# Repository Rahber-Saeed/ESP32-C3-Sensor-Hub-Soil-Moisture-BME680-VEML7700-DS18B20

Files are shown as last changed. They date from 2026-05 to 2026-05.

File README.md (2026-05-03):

# ESP32-C3-Sensor-Hub-Soil-Moisture-BME680-VEML7700-DS18B20
A feature-packed, portable open-source hardware sensor board built around the ESP32-C3. It integrates soil moisture monitoring, environmental sensing (BME680), light sensing (VEML7700), temperature sensing (DS18B20), complete Li-ion battery management (TP4056 + DW01A Protection), and automatic power switching.
# 🌱 ESP32-C3 Multi-Sensor & Plant Monitor Board

A compact, all-in-one development board designed for effortless IoT sensing and portable applications. It features a complete suite of sensors, robust Li-ion power management, and a convenient USB-C interface.

> ⚠️ **Note:** This is an open-source hardware project. Please refer to the BOM and Pick-And-Place files for the exact components required for assembly.

---

## ✨ Key Features

*   **Core Controller:** ESP32-C3 SuperMini (also compatible with ESP32-S3 SuperMini).
*   **Sensor Suites:**
    *   **🌱 Soil Moisture:** LM393 comparator with indicator LEDs and PH Connector.
    *   **🌫️ Environmental:** BME680 (Gas, Temp, Humidity, Pressure).
    *   **☀️ Light:** VEML7700 Ambient Light Sensor (I2C).
    *   **🌡️ Temperature:** DS18B20 One-Wire Digital Sensor.
*   **Power Management (Robust):**
    *   **TP4056:** Li-ion/Li-Po battery charging over USB-C.
    *   **DW01A + FS8205A:** Over-charge/Over-discharge protection.
    *   **Auto Power Switching:** Seamless transition between USB and Battery power via DMP1045U.
*   **Connectivity & Interface:**
    *   2x Qwiic I2C connectors for easy expansion.
    *   USB-C for data and charging.
    *   Status LEDs for Power, Bluetooth, and WiFi.
*   **User Controls:** Power Switch, Reset Button, Sleep Button.

---

## 🖼️ Gallery

Schematic_ESP-C3-supermini-based-Project_2026-05-03

| PCB Top | PCB Bottom | PCB 3D |
ESP-C3 supermini based Project_3D_Top_View

| :---: | :---: | :---: |

| PCB Top | PCB Bottom | PCB 3D |

*(Note: Ensure you place your uploaded images into an `images/` folder)*
ESP-C3 supermini based Project_3D_Bottom_View

---
ESP-C3 supermini based Project_2D_View

## 📜 Schematic & PCB

*   **Schematic:** [`Schematic_ESP-C3-supermini-based-Project_2026-05-03.pdf`](Schematic_ESP-C3-supermini-based-Project_2026-05-03.pdf)
*   **PCB Layout:** [`PCB_PCB_PCB_ESP-C3-supermini-based-Project_2025-07-15_2026-05-03.pdf`](PCB_PCB_PCB_ESP-C3-supermini-based-Project_2025-07-15_2026-05-03.pdf)

---

## 📦 Bill of Materials (BOM)

The complete BOM is available in the file [`BOM_ESP-C3-supermini-based-Project_2026-05-03.csv`](BOM_ESP-C3-supermini-based-Project_2026-05-03.csv).

| Component Type | Part | Description |
| :--- | :--- | :--- |
| **MCU** | ESP32-C3 SuperMini | Main WiFi/BLE Controller |
| **Power** | TP4056, DW01A, FS8205A | Battery Charger + Protection |
| **Sensors** | BME680, VEML7700, DS18B20 | Environmental, Light, Temp |
| **UI** | LM393, LEDs, Switches | Soil Moisture Detection, Status LEDs |

---

## 🔌 Pinout & Connections

This pinout is based on the provided schematic. Please verify with the final PCB layout.

| Function | Component | Pin (ESP32-C3 SuperMini) |
| :--- | :--- | :--- |
| **I2C** | SDA (VEML7700, BME680, Qwiic) | GPIO 5 |
| | SCL (VEML7700, BME680, Qwiic) | GPIO 4 |
| **OneWire** | DS18B20 | GPIO 2 |
| **Soil Moisture** | Digital Output (PH Connector U9) | GPIO 9 (SPI_CS1) |
| **Status LEDs** | WiFi Indicator (LED1) | GPIO 12 |
| | Bluetooth Indicator (LED2) | GPIO 13 |
| **Power** | Auto Power Switching P-MOSFET (Q1) | GPIO 0 |

*(Note: Pin mappings are based on the schematic. Refer to the ESP32-C3 datasheet for alternative configurations or if using the ESP32-S3 module).*

---

## 🛠️ Getting Started / Programming

1.  **Order the PCB:** Upload the `PCB_PCB_PCB...pdf` to a manufacturer like JLCPCB or PCBWay.
2.  **Solder Components:** Assemble the board using the BOM and Pick-And-Place CSV file.
3.  **Code Setup:**
    *   Select the `ESP32C3 Dev Module` in Arduino IDE or PlatformIO.
    *   **Libraries:**
        *   `Adafruit BME680`
        *   `Adafruit VEML7700`
        *   `OneWire` & `DallasTemperature` (for DS18B20).
4.  **Upload:** Connect via USB-C, select correct COM port, and upload your code.

---

## 📂 Repository Structure

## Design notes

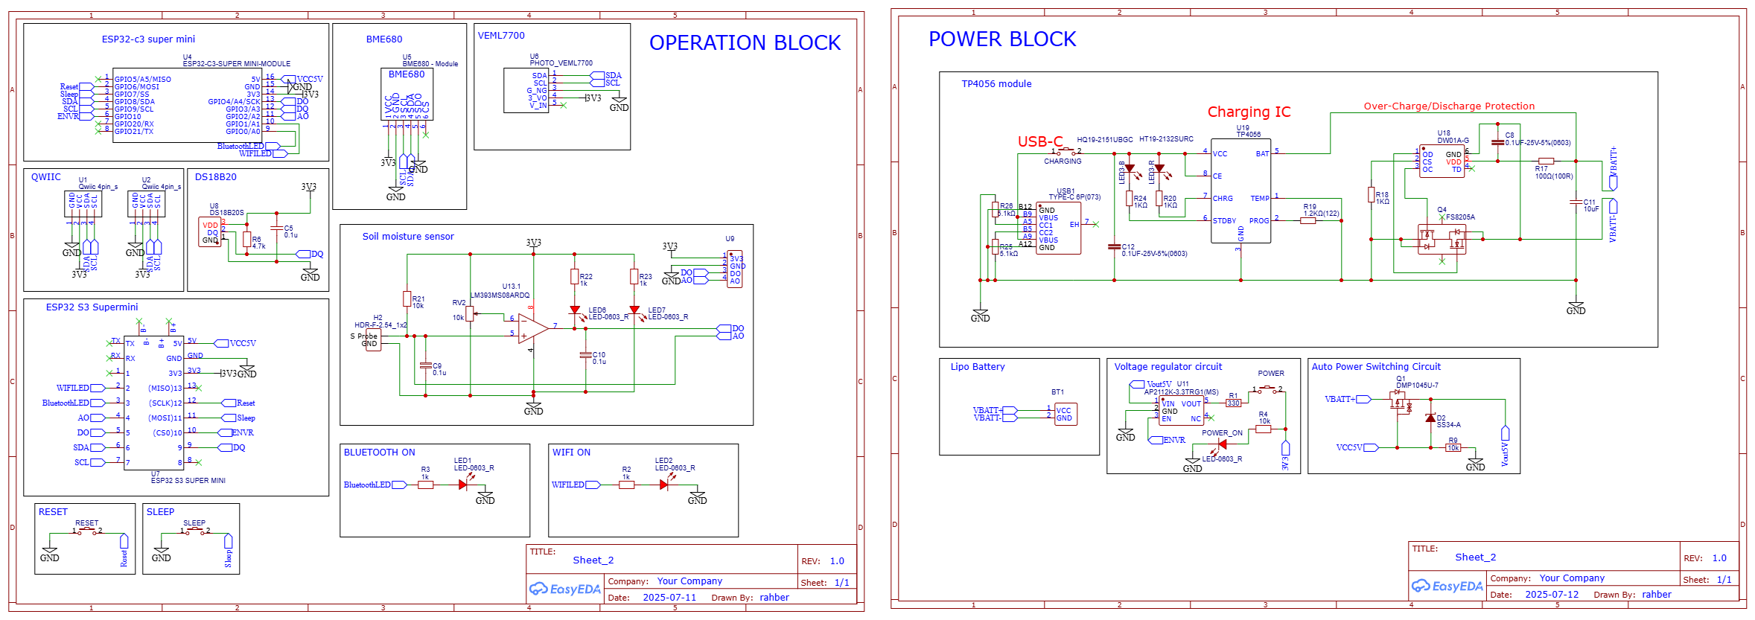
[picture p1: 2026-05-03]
Schematic_ESP-C3-supermini-based-Project_2026-05-03.png

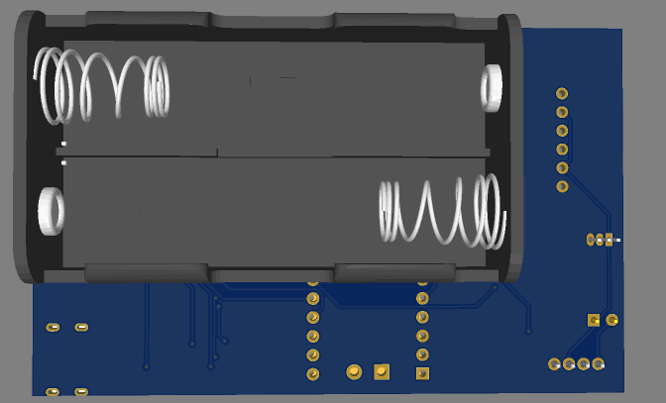
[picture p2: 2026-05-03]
ESP-C3 supermini based Project_3D_Bottom_View.png

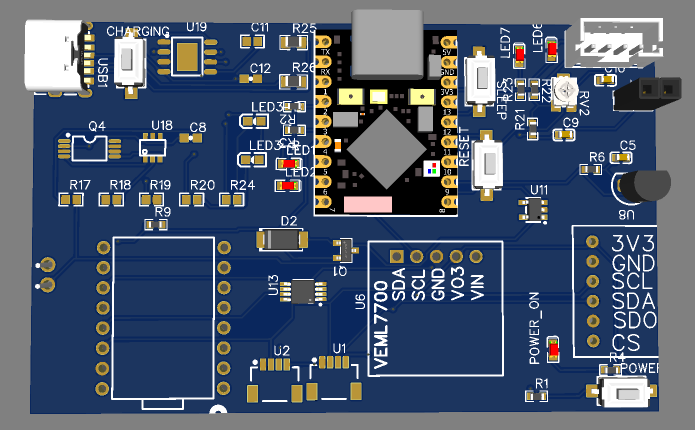
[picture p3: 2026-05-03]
ESP-C3 supermini based Project_3D_Top_View.png

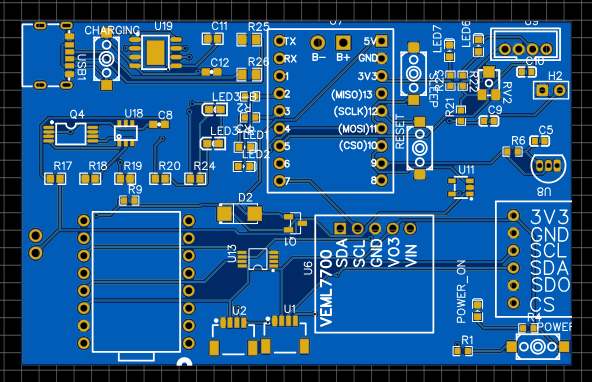
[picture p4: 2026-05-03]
ESP-C3 supermini based Project_2D_View.png

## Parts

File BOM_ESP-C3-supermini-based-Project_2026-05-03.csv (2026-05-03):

ID | Name | Designator | Footprint | Quantity | Manufacturer Part | Manufacturer | Supplier | Supplier Part | Price | Pins | 3DModel | Contributor | JLCPCB Part Class | LCSC Assembly | Package Display | Power (Watts) | Rated Voltage | Tolerance | image | link | subpart_no | 制造商
1 | 0.1u | C5,C9,C10 | C0603 | 3 |  |  |  |  |  | 2 | C0603_L1.6-W0.8-H0.8 | LCEDA_Lib |  |  |  |  |  |  |  | https://item.szlcsc.com/362304.html
2 | SS34-A | D2 | SMA_L4.3-W2.6-LS5.2-RD | 1 | SS34-A | FMS(美丽微) | LCSC | C143201 | 0.053 | 2 | SMA_L4.3-W2.6-LS5.2-RD | LCSC | Extended Part |  |  |  |  |  |  | https://item.szlcsc.com/34721.html
3 | LED-0603_R | LED6,LED7,LED1,LED2,POWER_ON | LED0603_RED | 5 | 19-217/R6C-AL1M2VY/3T | EVERLIGHT(台湾亿光) | LCSC | C72044 | 0.021 | 2 | LED0603_Red | LCEDA_01
4 | DMP1045U-7 | Q1 | SOT-23-3_L2.9-W1.3-P1.90-LS2.4-BR | 1 | DMP1045U-7 | DIODES(美台) | LCSC | C177033 | 0.159 | 3 | SOT-23-3P_L2.9-W1.3-H1.0-LS2.4-P0.95 | LCSC | Extended Part |  |  |  |  |  |  | https://www.diodes.com/assets/Package-Files/SOT23.pdf
5 | 4.7k | R6 | R0603 | 1 |  |  |  |  |  | 2 | R0603 | LCEDA_Lib |  |  |  |  |  |  |  | https://www.mouser.in/datasheet/2/447/PYu_RT_1_to_0_01_RoHS_L_11-1669912.pdf
6 | 10k | R9,R21,R4 | R0603 | 3 |  |  |  |  |  | 2 | R0603 | LCEDA_Lib |  |  |  |  |  |  |  | https://www.mouser.in/datasheet/2/447/PYu_RT_1_to_0_01_RoHS_L_11-1669912.pdf
7 | 1k | R22,R23,R2,R3 | R0603 | 4 |  |  |  |  |  | 2 | R0603 | LCEDA_Lib |  |  |  |  |  |  |  | https://www.mouser.in/datasheet/2/447/PYu_RT_1_to_0_01_RoHS_L_11-1669912.pdf
8 | 10k | RV2 | RES-ADJ-SMD_VG039NCH | 1 | 3*3Potentiometer-10kΩ20% | null | LCSC | C9900010776 |  | 3 | RES-ADJ-SMD_3P-L3.8-W3.0-H1.2-P1.90 | LCSC | Extended Part |  |  |  |  |  |  | https://item.szlcsc.com/139841.html
9 | ESP32-C3-SUPER MINI-MODULE | U4 | ESP32-C3-SUPER-MINI-MODULE | 1 |  |  |  |  |  | 16 |  | microactuator
10 | BME680 - Module | U5 | BME680PCB | 1 | New SchematicLib |  | DFRobot |  |  | 6 |  | chrisrisse
11 | PHOTO_VEML7700 | U6 | PHOTO_VEML7700_F | 1 | PHOTO_VEML7700 |  |  |  |  | 5 |  | shinkyusik
12 | DS18B20S | U8 | TO-92-3_L4.9-W3.7-P1.27-L | 1 | MYDS18B20S | Mysentech(敏源传感) | LCSC | C41361412 | 0.292 | 3 | TO-92-3_L4.9-W3.7-P1.27-L | lcsc |  |  |  |  |  |  |  | https://atta.szlcsc.com/upload/public/pdf/source/20180629/C233232_99576441F8ED8E9074FB1575A6BE3592.PDF
13 | PH-CONNECTOR 01.08.40.001.001 | U9 | CONN-TH_PH-CONNECTOR01.08.40.001.001 | 1 | PH-CONNECTOR 01.08.40.001.001 | null | LCSC | C9900005438 |  | 4 | CONN-TH_PH-CONNECTOR01.08.40.001.001 | LCSC | Extended Part |  |  |  |  |  |  | https://img.jlc.com/image//data/smt-stock-produce/componentSizePhoto/2022-01-04/19bec1aa099f49cab68d79e3ac0b8296/BG2112310476_D21122700130_font.png
14 | AP2112K-3.3TRG1(MS) | U11 | SOT-23-5_L2.9-W1.6-P0.95-LS2.7-BR | 1 | AP2112K-3.3TRG1(MS) | MSKSEMI(美森科) | LCSC | C22365427 | 0.073 | 5 | SOT-23-5_L2.9-W1.6-P0.95-LS2.7-BR | lcsc | Extended Part |  |  |  |  |  |  | https://atta.szlcsc.com/upload/public/pdf/source/20210222/C616245_2EB3813F1C3E67808D09ADFA7C45AA77.pdf
15 | LM393MS08ARDQ | U13 | MSOP-8_L3.0-W3.0-P0.65-LS4.9-BL-1 | 1 | LM393MS08ARDQ | GR(国睿) | LCSC | C46527059 | 0.089 | 8 | MSOP-8_L3.0-W3.0-P0.65-LS4.9-BL-1 | lcsc | Extended Part |  |  |  |  |  |  | https://atta.szlcsc.com/upload/public/pdf/source/20200925/C726653_8C4DEEE918D81B4566489376FD74F88A.pdf | 1
16 | HDR-F-2.54_1x2 | H2 | HDR-F-2.54_1X2 | 1 |  |  | LCSC | C49661 | 0.061 | 2 | HDR-F-2.54_1x2 | LCEDA_Lib
17 | ESP32 S3 SUPER MINI | U7 | ESP32-S3-SUPERMINI-MAXS | 1 |  |  |  |  |  | 20 | SuperMini ESP32-S3_TrueSize | maxanthonyfloreztapia
18 | 0.1UF-25V-5%(0603) | C8,C12 | 0603-CAP | 2 | ? |  |  |  |  | 2 |  | SparkFun
19 | 10uF | C11 | 0603 | 1 | 0603X106K160NT | FH | LCSC | C70225 | 0.029 | 2 |  |  |  |  |  |  | 16V | ±10%
20 | HQ19-2151UBGC | LED3-B | LED-0603 | 1 | HQ19-2151UBGC | HARVATEK | LCSC | C154450 |  | 2 |  | LCSC
21 | HT19-2132SURC | LED3-R | LED-0603 | 1 | HT19-2132SURC | HARVATEK | LCSC | C154453 |  | 2 |  | LCSC
22 | FS8205A | Q4 | TSSOP-8_3X4.4X065P | 1 | FS8205A | FORTUNE | LCSC | C16052 | 0.119 | 8 |  | Guest |  | Yes |  |  |  |  | //image.lceda.cn/szlcsc/C16052.jpg
23 | 100Ω(100R) | R17 | 0603 | 1 | AC0603FR-07100RL | YAGEO | LCSC | C125923 | 0.002 | 2 |  |  |  |  |  | 1/10W |  | ±1%
24 | 1KΩ | R18,R20,R24 | 0603 | 3 | RC0603FR-071KL | YAGEO | LCSC | C22548 | 0.002 | 2 |  |  |  |  |  | 1/10W |  | ±1%
25 | 1.2KΩ(122) | R19 | 0603 | 1 | RC0603JR-071K2L | YAGEO | LCSC | C114679 | 0.002 | 2 |  |  |  |  |  | 1/10W |  | ±5%
26 | 5.1kΩ | R25,R26 | R0805 | 2 | 0805W8F5101T5E | UNI-ROYAL(厚声) | LCSC | C27834 | 0.003 | 2 | R0805_L2.0-W1.3-H0.6 | lcsc | Basic Part |  |  |  |  |  |  | https://item.szlcsc.com/142685.html
27 | DW01A-G | U18 | SOT-23-6 | 1 | DW01A-G | FORTUNE | LCSC | C61503 | 0.078 | 6 |  | LCSC
28 | TP4056 | U19 | SOP-8_EP_150MIL | 1 | TP4056 | TOPPOWER | LCSC | C16581 | 0.186 | 9 |  | Guest |  | Yes | No |  |  |  | //image.lceda.cn/szlcsc/C16581.jpg
29 | Qwiic 4pin_s | U1,U2 | QWIIC 4PIN | 2 |  |  |  |  |  | 6 |  | PeterL
30 | TYPE-C 6P(073) | USB1 | TYPE-C-SMD_TYPE-C-6P-073 | 1 | TYPE-C 6P(073) | SHOU HAN(首韩) | LCSC | C668623 | 0.04 | 10 | TYPE-C-SMD_TYPE-C-6P-073 | LCSC | Extended Part |  |  |  |  |  |  | https://item.szlcsc.com/datasheet/TYPE-C%25206P(073)/698566.html
31 | K2-3.6×6.1_SMD | CHARGING,POWER,RESET,SLEEP | KEY-SMD_2P-L6.2-W3.6-LS8.0 | 4 | K2-1107ST-A4SW-06 |  | LCSC | C118141 | 0.074 | 2 | KEY-SMD_2P-L6.2-W3.6-LS8.0 | LCEDA_Lib |  |  |  |  |  |  |  | https://so.szlcsc.com/global.html?c=&k=C498306 |  | 韩国韩荣
32 | 330 | R1 | R0603 | 1 |  |  |  |  |  | 2 | R0603 | LCEDA_Lib |  |  |  |  |  |  |  | https://www.mouser.in/datasheet/2/447/PYu_RT_1_to_0_01_RoHS_L_11-1669912.pdf
33 | No.52Section side by side battery box | BT1 | BAT-TH_BC2AA | 1 | 五号2节并列电池盒 | 国产 | LCSC | C5404 |  | 2 | BAT-TH_BC2AA | 立创EDA官方封装库 | Extended Part |  |  |  |  |  |  | https://atta.szlcsc.com/upload/public/pdf/source/20120922/1457706536101.pdf

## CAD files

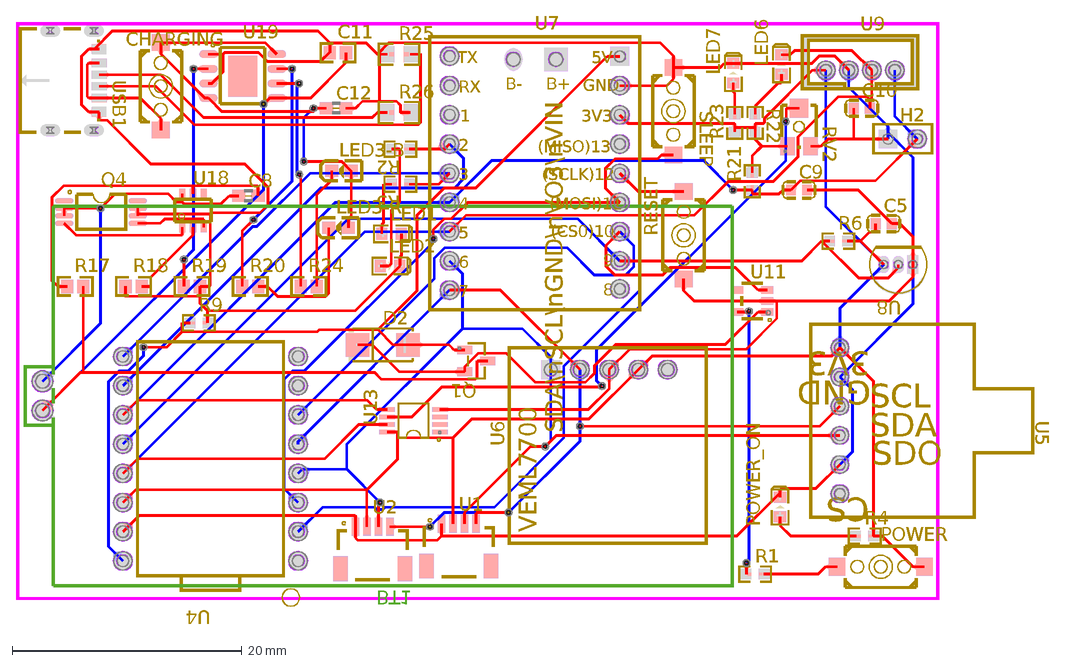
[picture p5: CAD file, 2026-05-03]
PCB_PCB_ESP-C3-supermini-based-Project_2025-07-15_2026-05-03.dxf
C5
C9
C10
D2
LED6
LED7
Q1
R6
R9
R21
R22
R23
RV2
U4
U5
3V3
SCL
CS
GND
SDA
SDO
U6
SDA\nSCL\nGND\nVO3\nVIN
VEML7700
U8
U9
U11
U13
H2
U7
B+
B-
5V
(MISO)13
(SCLK)12
(MOSI)11
(CS0)10
9
8
7
6
5
4
3
2
1
RX
TX
C8
C11
C12
LED3-B
LED3-R
Q4
R17
R18
R19
R20
R24
R25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

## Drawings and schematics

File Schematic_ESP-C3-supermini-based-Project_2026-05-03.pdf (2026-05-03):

OPERATION BLOCK | POWER BLOCK

# Charging IC

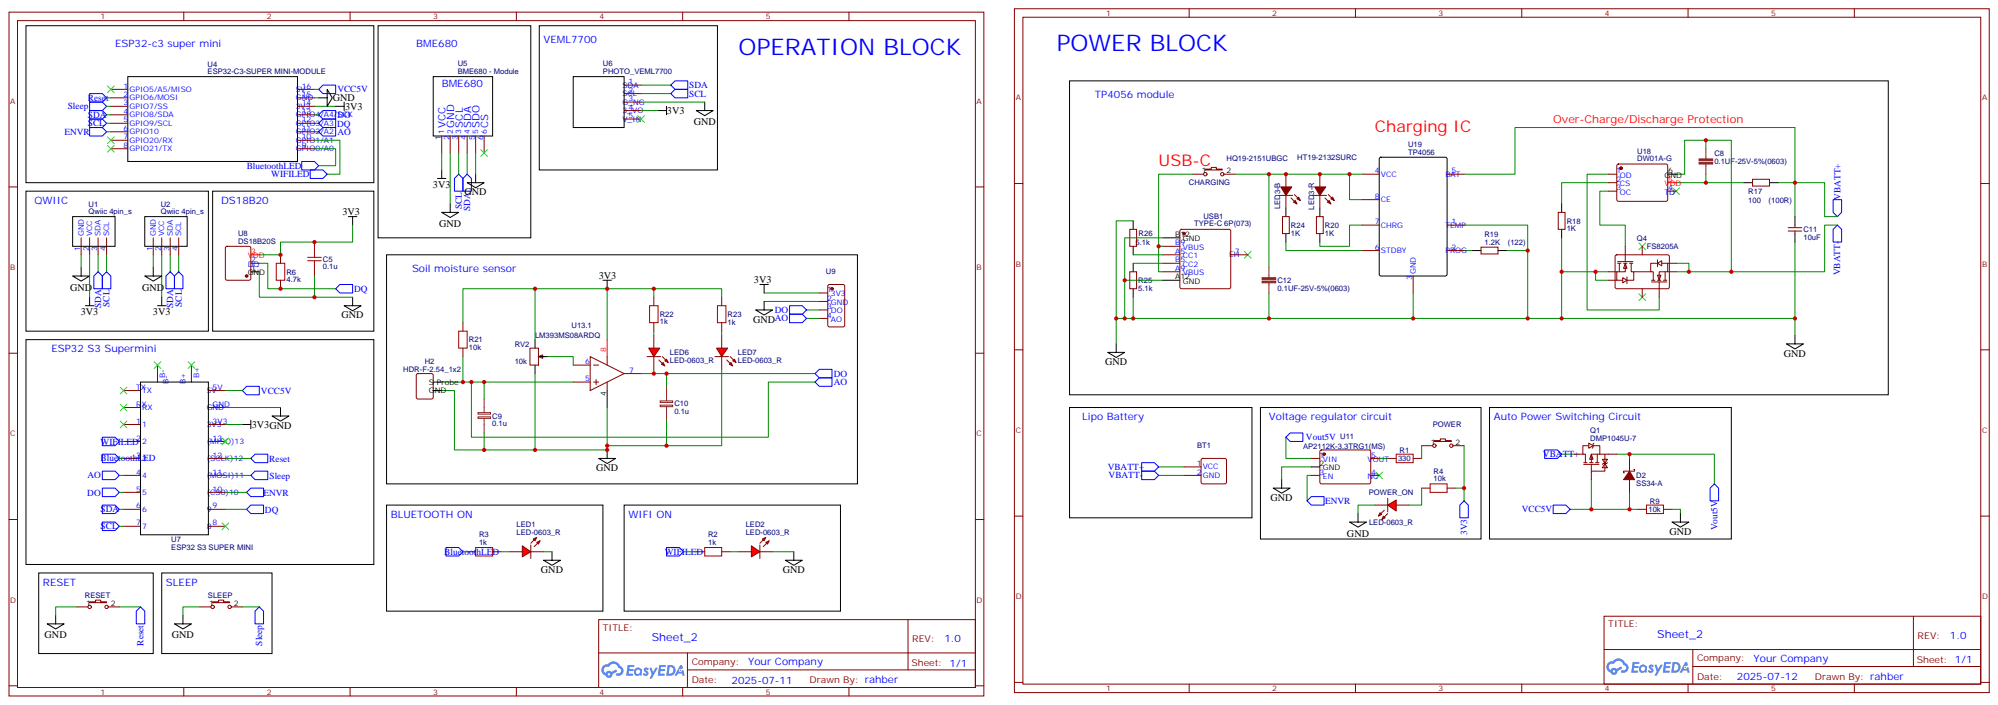
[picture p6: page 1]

BME680 - Module
BME680 VCC GND SCL SDA SDO CS

Over-Charge/Discharge Protection

Auto Power Switching Circuit
